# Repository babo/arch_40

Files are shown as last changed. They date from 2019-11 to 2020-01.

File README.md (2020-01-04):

## Arch 40

assembled_keyboard_1
assembled_keyboard_2

#### Case Renders:
case_render_1
case_render_2

#### Switch Plate:
switch_plate_render

## 40% Ortholinear + Columnar Stagger Keyboard
* Inspired by the Ergodox, Atreus, Iris, Corne, and probably others

* Design goals:
    * Efficiency and minimalism of a 40% form factor
    * Ergo benefits of tilted columnar stagger layout
    * Ease of use coming from ANSI style layouts
    * Simplicity of a non-split keyboard
    * Compatability with Ergodox style keysets
    * Compatible with Cherry MX, Alps, and Kailh Choc switches

----

## Assembly:
* Stacked acrylic layer case, acrylic/metal switch plate 
    * Layer dimensions and path lengths are outlined in `path_length.md`
    * Alternatively, there is a 2-part case in `./cad_files/stl_files/3d_print_case` designed to be 3D printed and fastened together with machine screws
* Can be built with a PCB and microcontroller, or can be handwired with a microcontroller
* Files for laser cutting by Ponoko/other services in `./illustrator_files` and `./inkscape_files`
    * `./illustrator_files` includes case layer DXF files imported into Adobe Illustrator at 1:1 scale with units in millimeters
        * `final_cut_layout.eps` is Ponoko's P3 size template with case layers, **without plate**
            * Use this if you choose to go with a metal plate
        * `final_cut_layout_plate.eps` is Ponoko's P3 size template with case layers, **with plate**
            * Use this if you choose to go with an acrylic plate

    * `./inkscape_files` includes pdf-compatible Adobe `.ai` files as well as `.SVG` files of the case layers and plate
____

#### Component list:
* Acrylic case layers + plate
* PCB (optional, can be handwired as well)
    * Pro Micro (PCB is designed to use this microcontroller)
    * Teensy2.0 (if handwiring and not using PCB)
* (49) Cherry MX style switches
* (1) 2u Cherry style stabilizer
    * **Plate-mounted** works perfectly with 1.5mm metal switch plate
    * **Requires some modification** to work properly with 3.0mm acrylic plate
* Adafruit USB-mini breakout board (or a simple female USB-mini)
* WS2812B LED strips (optional)
* (49) 1N4184 diodes
* M2 Standoffs and screws
    * 5mm screw length
    * 10mm standoff length for use with a **1.5mm metal plate**
    * 12mm standoff length for use with a **3.0mm acrylic plate**

____

#### Case Stack Order:
1) `arch_40_case_layer0`
2) `arch_40_plate`
3) `arch_40_case_layer2-3`
4) `arch_40_case_layer2-3` (repeated)
5) `arch_40_case_layer4`
7) `arch_40_case_layer5`

* **Note:** `arch_40_case_layer2-3` is intended to be used twice, it contains the cutout for the USB connection

____

#### PCB:
##### Revision history:
* rev 0: prototype, designed by [ibnuda](https://github.com/ibnuda)
* rev 1: better case fitment, functionally same as rev 0
* rev 1.1: added support for MX, Alps, Kailh Choc switches

----

* QMK files for PCB firmware in `./firmware/qmk_files`
* PCB can be made by sending the zipped gerber files in `./pcb/gerbers/arch_40_rev1.1_gerber.zip` to a PCB prototyping service such as [JLCPCB](https://jlcpcb.com)
* **Note**: The Pro Micro controller needs to be soldered onto the PCB as close as possible, need to remove the spacers on the headers of the Pro Micro

----

pcb_image

##### Pro Micro Pinout:
* Diode direction: row to column
* Column 0 = ESC key column
* Row 0 = QWERTY row
~~~
Rows:              Columns:                            LED:
-----------------------------------------------------------------
r0 : D3            c0 : F4         c6 : B2             vcc : VCC
r1 : D1            c1 : F5         c7 : B6             gnd : GND
r2 : D0            c2 : F6         c8 : B5            data : D2
r3 : D4            c3 : F7         c9 : B4
                   c4 : B1        c10 : E6
                   c5 : B3        c11 : D7
                                  c12 : C6
~~~
____

#### Handwiring:

##### Matrix:
matrix

##### Teensy2.0 Pinout:
* Diode direction: column to row
* Column 0 = ESC key column
* Row 0 = QWERTY row
~~~
Rows:               Columns:                            LED:
-----------------------------------------------------------------
r0 : F0             c0 : F7         c6 : C6             vcc : VCC
r1 : F1             c1 : B6         c7 : D3             gnd : GND
r2 : F4             c2 : B5         c8 : D2            data : B1 
r3 : F5             c3 : B4         c9 : D1
r4 : F6             c4 : D7        c10 : D0
                    c5 : C7        c11 : B7
~~~

##### Wiring Example:
wiring_example_no_led

##### Wiring Example With Underglow LED's:
wiring_example_with_led

## Firmware Flashing:

#### PCB Builds:
##### Linux:
* The Pro Micro controller can be flashed with [avrdude](https://www.nongnu.org/avrdude/)

    * Navigate to the `./firmware` directory to flash the `arch40firmware_pcb.hex` file:

    `$ avrdude -p atmega32u4 -P /dev/ttyACM0 -c avr109 flash:w:arch40firmware_pcb.hex`

    * Or to the `./firmware/qmk_files` to flash the `arch40_promicro_default.hex` file

    `$ avrdude -p atmega32u4 -P /dev/ttyACM0 -c avr109 flash:w:arch40_promicro_default.hex`

* They are the same keymap, the former was created with Keyboard Firmware Builder, and the latter with QMK

##### Windows/MacOS:
* Can be done using [QMK Toolbox](https://github.com/qmk/qmk_toolbox)

##### LED Backlighting:
* Default firmware `arch40firmware_pcb.hex` and `arch40_promicro_default.hex` includes configuration for WS2812B LED backlighting strips
    * The data pin for the LED's is set to pin D2 on the Pro Micro
    * Default 12 LED quantity, 10 backlight brightness levels, variable color hue
    * To change the LED configuration:
        1) The `arch40firmware_pcb.json` file can be uploaded to [Keyboard Firmware Builder](https://kbfirmware.com/) and edited/recompiled as desired
        2) The QMK source files can be edited manually in a text editor
____

#### Handwired Builds:
* Linux:
    * The Teensy2.0 controller can be flashed with the [teensy-loader-cli](https://www.pjrc.com/teensy/loader_cli.html)

~~~
$ teensy-loader-cli --mcu=atmega32u4 -w -v ./firmware/arch40firmware_hw.hex
~~~
* MacOS/Windows:
    * Can be flashed with the [Teensy Loader Application](https://www.pjrc.com/teensy/loader.html)
    * Or can be done using [QMK Toolbox](https://github.com/qmk/qmk_toolbox)
##### LED Backlighting:
* Default firmware `arch40firmware_hw.hex` includes configuration for WS2812B LED backlighting strips
    * The data pin for the LED's is set to pin B1 on the Teensy2.0

## Note:
* Kerf of plate and case layers is set to 0.15mm (typical for Ponoko/ Laserboost/ Lasergist)

## To-do:
* Add image of default keymap

###### Model was created in Solidworks, then exported as STL/DXF. Feel free to use/modify/redistribute.

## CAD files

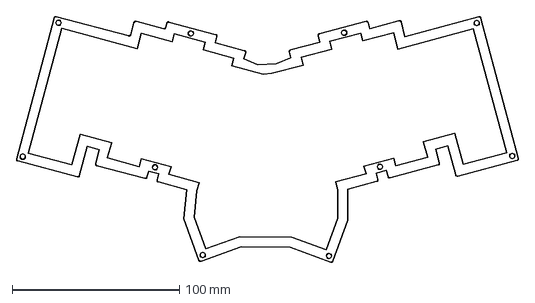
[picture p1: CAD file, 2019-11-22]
cad_files/dxf_files/arch_case_40_layer4.DXF
300.3 x 147.2 mm

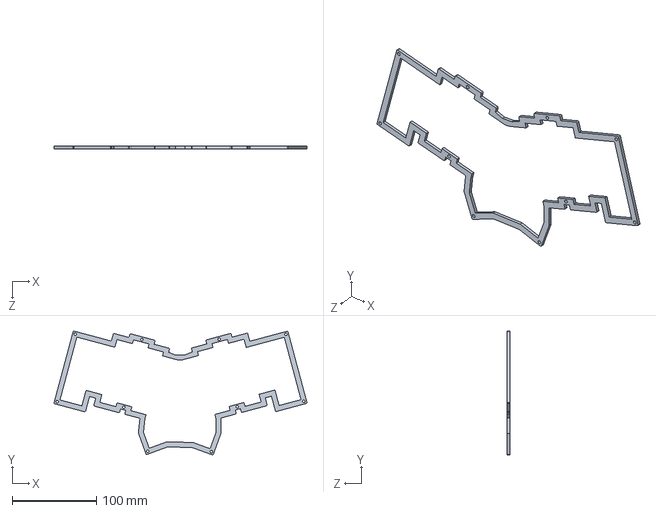
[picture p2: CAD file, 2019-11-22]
cad_files/sldprt_files/arch_40_case_layer4.SLDPRT
300.3 x 147.0 x 3.00 mm

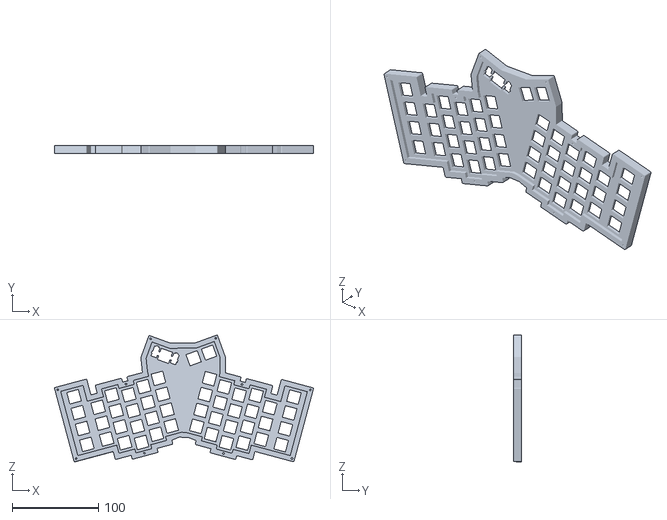
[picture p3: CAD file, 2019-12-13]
cad_files/stl_files/3d_print_case/3d_print_case_1.STL
300.3 x 9.00 x 147.0

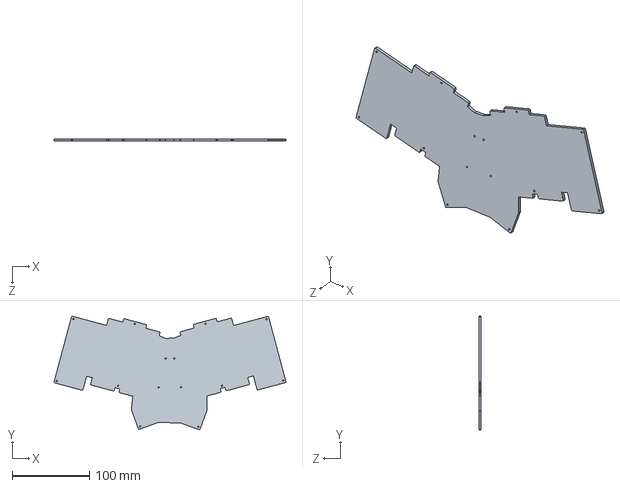
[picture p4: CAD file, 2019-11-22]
cad_files/sldprt_files/arch_40_case_layer5.SLDPRT
300.3 x 147.0 x 3.00 mm

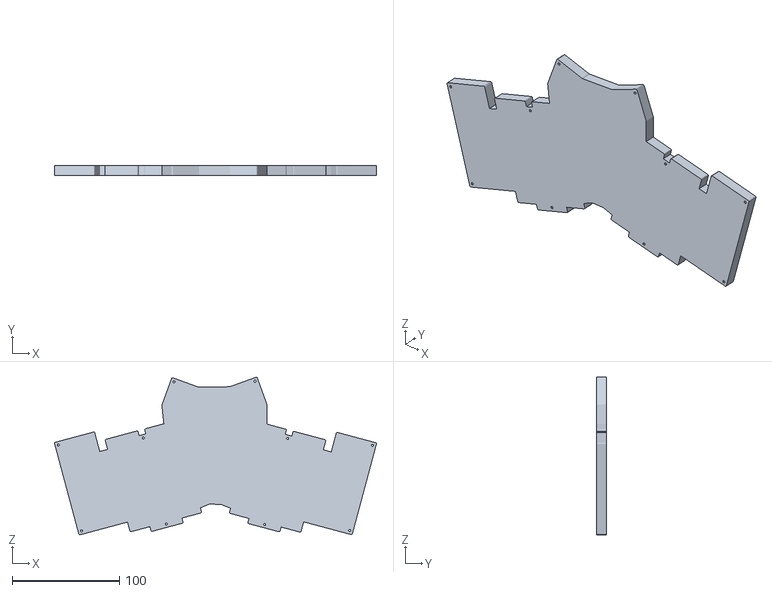
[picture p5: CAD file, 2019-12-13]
cad_files/stl_files/3d_print_case/3d_printed_case_2.STL
300.3 x 9.00 x 147.0

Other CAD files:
cad_files/dxf_files/arch_40_case_layer5.DXF
cad_files/stl_files/arch_40_case_layer4.STL
cad_files/stl_files/arch_40_case_layer5.STL

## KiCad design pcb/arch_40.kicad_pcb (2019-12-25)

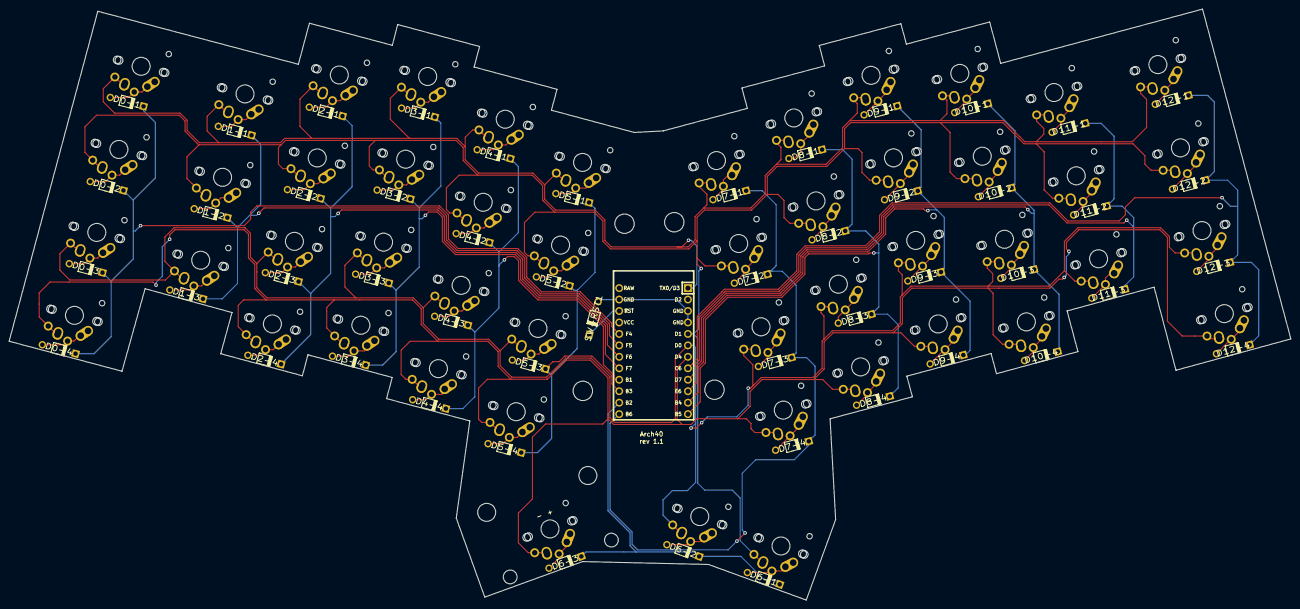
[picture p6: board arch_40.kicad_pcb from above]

Board: 2 copper layers, 284.2 x 131.0 mm, 100 parts (1 on the bottom side), 68 nets.

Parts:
D0-1, D0-2, D0-3, D0-4, D1-1, D1-2, D1-3, D2-1, D2-2, D2-3, D2-4, D3-1, D3-2, D3-3, D3-4, D4-1, D4-2, D4-3, D4-4, D5-1, D5-2, D5-3, D5-4, D6-1, D6-2, D6-3, D7-1, D7-2, D7-3, D7-4, D8-1, D8-2, D8-3, D8-4, D9-1, D9-2, D9-3, D9-4, D10-1, D10-2, D10-3, D10-4, D11-1, D11-2, D11-3, D12-1, D12-2, D12-3, D12-4: DIODE; Diode
SW0-1, SW0-2, SW0-3, SW0-4, SW1-1, SW1-2, SW1-3, SW2-1, SW2-2, SW2-3, SW2-4, SW3-1, SW3-2, SW3-3, SW3-4, SW4-1, SW4-2, SW4-3, SW4-4, SW5-1, SW5-2, SW5-3, SW5-4, SW6-1, SW6-2, SW7-1, SW7-2, SW7-3, SW7-4, SW8-1, SW8-2, SW8-3, SW8-4, SW9-1, SW9-2, SW9-3, SW9-4, SW10-1, SW10-2, SW10-3, SW10-4, SW11-1, SW11-2, SW11-3, SW12-1, SW12-2, SW12-3, SW12-4: SWITCH_PUSH; MX-Alps-Choc-1U-NoLED
SW6-3: SWITCH_PUSH; MX-Alps-Choc-2U-StabNormal-noled-alt
SW-RST1: SWITCH_PUSH; Diode
U1: ARDUINO_PRO_MICRO; ArduinoProMicro

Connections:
/COL0: D0-1.2, D0-2.2, D0-3.2, D0-4.2, U1.20
/COL1: D1-1.2, D1-2.2, D1-3.2, U1.19
/COL2: D2-1.2, D2-2.2, D2-3.2, D2-4.2, U1.18
/COL3: D3-1.2, D3-2.2, D3-3.2, D3-4.2, U1.17
/COL4: D4-1.2, D4-2.2, D4-3.2, D4-4.2, U1.16
/COL5: D5-1.2, D5-2.2, D5-3.2, D5-4.2, U1.15
/COL6: D6-1.2, D6-2.2, D6-3.2, U1.14
/COL7: D7-1.2, D7-2.2, D7-3.2, D7-4.2, U1.13
/COL8: D8-1.2, D8-2.2, D8-3.2, D8-4.2, U1.12
/COL9: D9-1.2, D9-2.2, D9-3.2, D9-4.2, U1.11
/COL10: D10-1.2, D10-2.2, D10-3.2, D10-4.2, U1.10
/COL11: D11-1.2, D11-2.2, D11-3.2, U1.9
/COL12: D12-1.2, D12-2.2, D12-3.2, D12-4.2, U1.8
/ROW-1: SW0-1.1, SW1-1.1, SW2-1.1, SW3-1.1, SW4-1.1, SW5-1.1, SW7-1.1, SW8-1.1, SW9-1.1, SW10-1.1, SW11-1.1, SW12-1.1, U1.1
/ROW-2: SW0-2.1, SW1-2.1, SW2-2.1, SW3-2.1, SW4-2.1, SW5-2.1, SW6-1.1, SW7-2.1, SW8-2.1, SW9-2.1, SW10-2.1, SW11-2.1, SW12-2.1, U1.5
/ROW-3: SW0-3.1, SW1-3.1, SW2-3.1, SW3-3.1, SW4-3.1, SW5-3.1, SW6-2.1, SW7-3.1, SW8-3.1, SW9-3.1, SW10-3.1, SW11-3.1, SW12-3.1, U1.6
/ROW-4: SW0-4.1, SW2-4.1, SW3-4.1, SW4-4.1, SW5-4.1, SW6-3.1, SW7-4.1, SW8-4.1, SW9-4.1, SW10-4.1, SW12-4.1, U1.7
GND: SW-RST1.1, U1.3, U1.4, U1.23
unnamed: D0-1.1, SW0-1.2
unnamed: D0-2.1, SW0-2.2
unnamed: D0-3.1, SW0-3.2
unnamed: D0-4.1, SW0-4.2
unnamed: D1-1.1, SW1-1.2
unnamed: D1-2.1, SW1-2.2
unnamed: D1-3.1, SW1-3.2
unnamed: D2-1.1, SW2-1.2
unnamed: D2-2.1, SW2-2.2
unnamed: D2-3.1, SW2-3.2
unnamed: D2-4.1, SW2-4.2
unnamed: D3-1.1, SW3-1.2
unnamed: D3-2.1, SW3-2.2
unnamed: D3-3.1, SW3-3.2
unnamed: D3-4.1, SW3-4.2
unnamed: D4-1.1, SW4-1.2
unnamed: D4-2.1, SW4-2.2
unnamed: D4-3.1, SW4-3.2
unnamed: D4-4.1, SW4-4.2
unnamed: D5-1.1, SW5-1.2
unnamed: D5-2.1, SW5-2.2
unnamed: D5-3.1, SW5-3.2
unnamed: D5-4.1, SW5-4.2
unnamed: D6-1.1, SW6-1.2
unnamed: D6-2.1, SW6-2.2
unnamed: D6-3.1, SW6-3.2
unnamed: D7-1.1, SW7-1.2
unnamed: D7-2.1, SW7-2.2
unnamed: D7-3.1, SW7-3.2
unnamed: D7-4.1, SW7-4.2
unnamed: D8-1.1, SW8-1.2
unnamed: D8-2.1, SW8-2.2
unnamed: D8-3.1, SW8-3.2
unnamed: D8-4.1, SW8-4.2
unnamed: D9-1.1, SW9-1.2
unnamed: D9-2.1, SW9-2.2
unnamed: D9-3.1, SW9-3.2
unnamed: D9-4.1, SW9-4.2
unnamed: D10-1.1, SW10-1.2
unnamed: D10-2.1, SW10-2.2
unnamed: D10-3.1, SW10-3.2
unnamed: D10-4.1, SW10-4.2
unnamed: D11-1.1, SW11-1.2
unnamed: D11-2.1, SW11-2.2
unnamed: D11-3.1, SW11-3.2
unnamed: D12-1.1, SW12-1.2
unnamed: D12-2.1, SW12-2.2
unnamed: D12-3.1, SW12-3.2
unnamed: D12-4.1, SW12-4.2
unnamed: SW-RST1.2, U1.22

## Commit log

2019-11-13 fixed cutout.
    [arch_40.kicad_pcb]
2019-11-14 added zipped gerber files
2019-11-19 added pcb firmware
2019-11-21 updated pcb rev1
    [arch_40.kicad_pcb]
2019-11-22 updated pcb firmware
2019-11-22 updated case filenames
    [arch_40_case_layer4-5.DXF, arch_40_case_layer4-5.SLDPRT, arch_40_case_layer4-5.STL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]
2019-11-23 revert case layer filenames
    [arch_40_case_layer4.SLDPRT, arch_40_case_layer4.STL, arch_40_case_layer5.DXF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]
2019-12-13 added STL files for 3d printing
    [3d_print_case_1.STL, 3d_printed_case_2.STL]
2019-12-25 updated pcb rev1.1
    [arch_40-B_Cu.gbr, arch_40-B_Mask.gbr, arch_40-B_Paste.gbr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]
